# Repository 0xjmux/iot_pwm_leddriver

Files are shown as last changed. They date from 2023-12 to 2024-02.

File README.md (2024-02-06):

# IoT driver for "Dumb" 5050 RGB LED Strips
ESP8266-based LED Driver designed to work with WLED and cheap 12V barrel-jack power supplies for accent lighting around the home. 

<p align="center">

</p>

This driver was designed to allow network-enabled control of almost any 12V "dumb" strip around, from plain white to FCOB strips to RGBW. 

My v1.0 worked perfectly, so I'm going to leave it as-is. The only upgrades I'd make at this point are: 
1) WLED announced that they're deprecating ESP8266 support right after I ordered v1.0, but for driving a single color the ESP8266 should be more than enough. 
2) There's some whine from the Power mosfet drivers, but it's barely noticable and not really worth addressing unless I was already doing a redesign. 

***See [Releases](https://github.com/0xjmux/iot_pwm_leddriver/releases) for all the necessary files and information to make your own!***

### Features
* Uses mini blade fuses for overcurrent protection and to protect against fire hazard from shorts on bad quality LED strips
* Board designed to handle up to and above maximum expected from most LED strips (8A)
* 4 channels to handle RGBW: or up to 4 single-color strips
* Terminal block for ease of use connecting strips and a 2.1mm jack allowing use of cheap 12V supplies you have lying around
* Capable of both programming and debug over [SOICbite Connector](https://github.com/SimonMerrett/SOICbite).
* Includes status and power LEDs and board overvoltage protection

<p align="center">
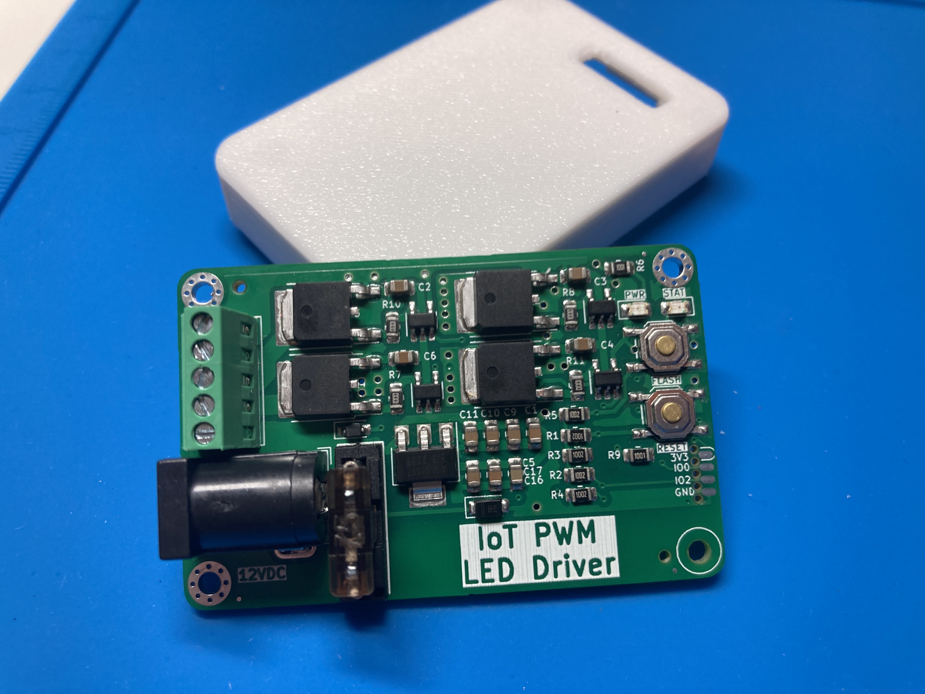
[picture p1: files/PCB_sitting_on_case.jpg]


</p>

* See [ABOUT.md](./ABOUT.md) for some information about design goals and the project. 

#### Pinout 

| Output | ESP Pin |
| ----- | ---  |
| LED_R | GPIO 5  |
| LED_G | GPIO 13 |
| LED_B | GPIO 14 |
| LED_W | GPIO 12 |
| STATUS LED | GPIO 16 |

#### Case
I also designed a 3D printable case, which can be found under [case/](case/). The screw terminals are still easily accessible, and there's a window on the bottom so you can see the board name and version without having to open it. 
* The case uses M2x8mm screws to hold the two halves together, and is designed to be printed in PLA with 10% infill. 

<p align="center">
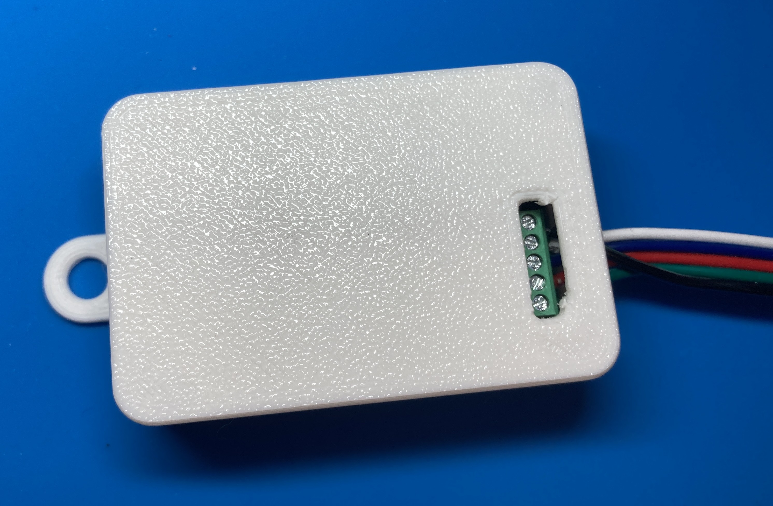
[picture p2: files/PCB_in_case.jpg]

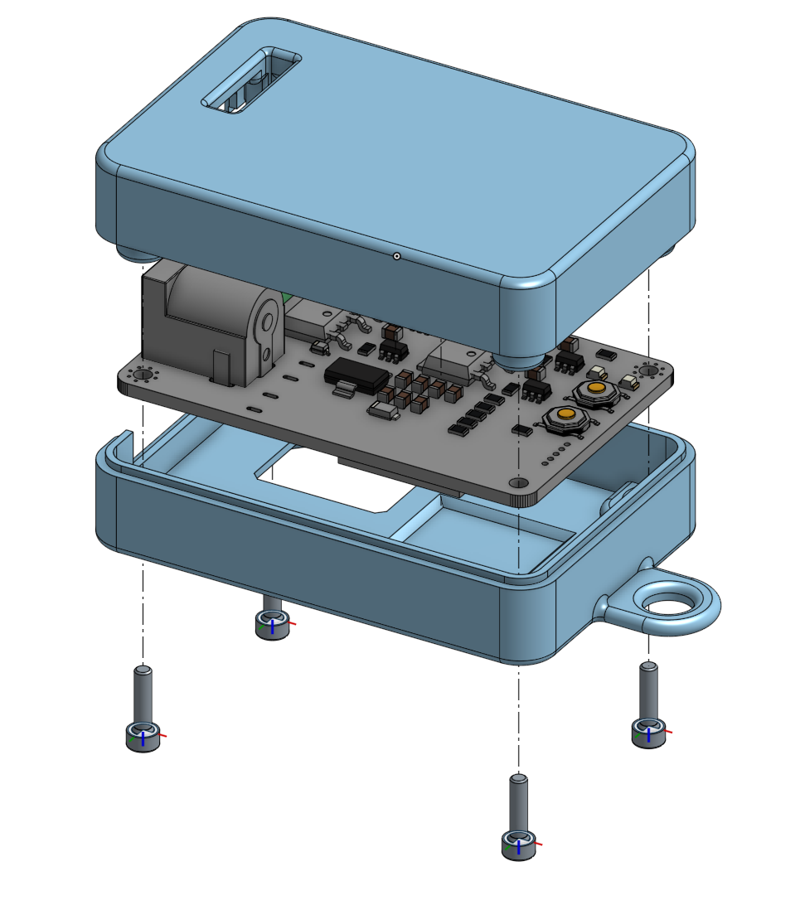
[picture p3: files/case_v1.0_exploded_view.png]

</p>

### v1.0 - First try works!
* Complete redesign from v0.2, with a focus on overall system design and ease of setup for the end user. 
* Uses mini blade fuses for overcurrent protection and to protect against fire hazard from shorts on bad quality LED strips
* Board designed to handle up to and above maximum expected from most LED strips (8A)
* 4 channels to handle RGBW: or up to 4 single-color strips
* Terminal block for ease of use connecting strips and a 2.1mm jack allowing use of cheap 12V supplies you have lying around
* Capable of both programming and debug over [SOICbite Connector](https://github.com/SimonMerrett/SOICbite).
* Includes status and power LEDs and board overvoltage protection

<p align="center">
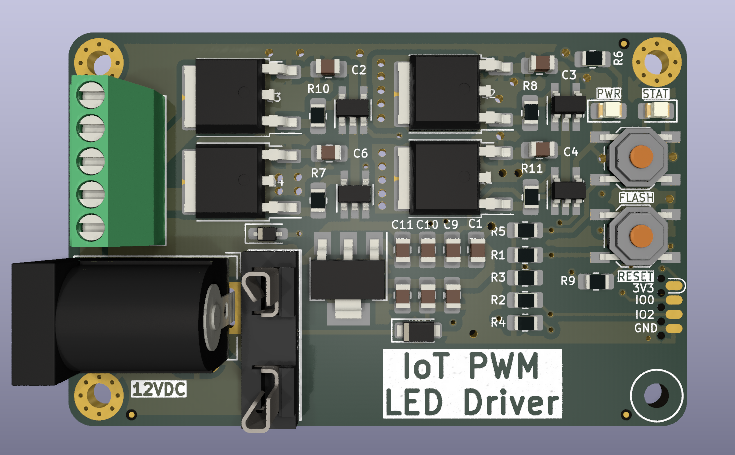
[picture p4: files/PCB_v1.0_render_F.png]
v1.0 PCB Render Front

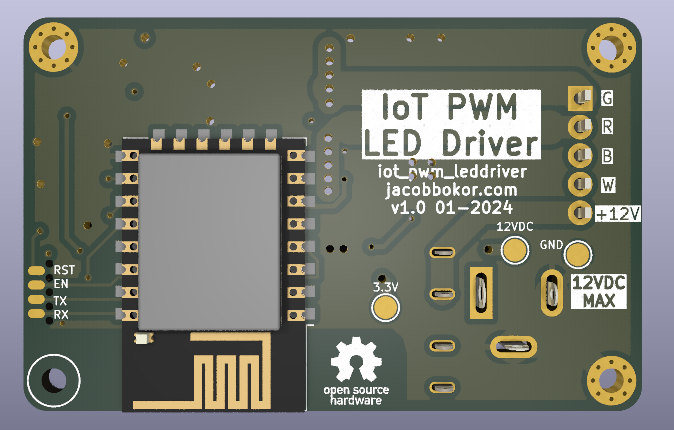
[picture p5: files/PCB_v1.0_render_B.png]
v1.0 PCB Render Back

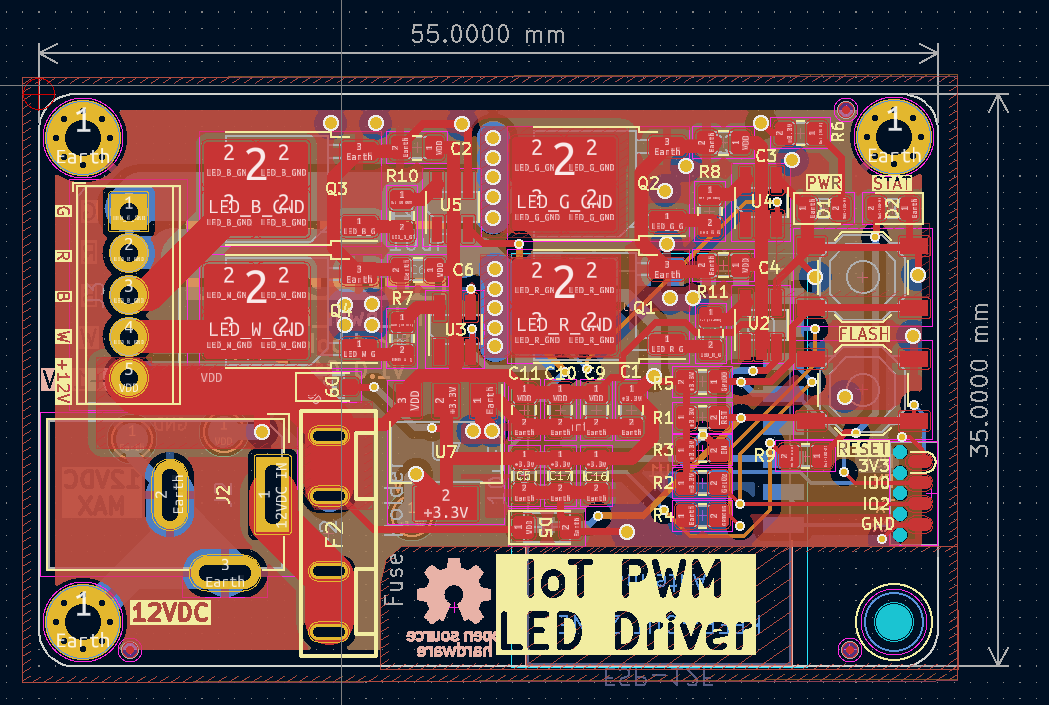
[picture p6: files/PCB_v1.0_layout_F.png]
v1.0 PCB Layout

</p>

### v0.1 - Quick Board Mock-up
* My first 4 layer board! But some improvement still possible
 
<p align="center">
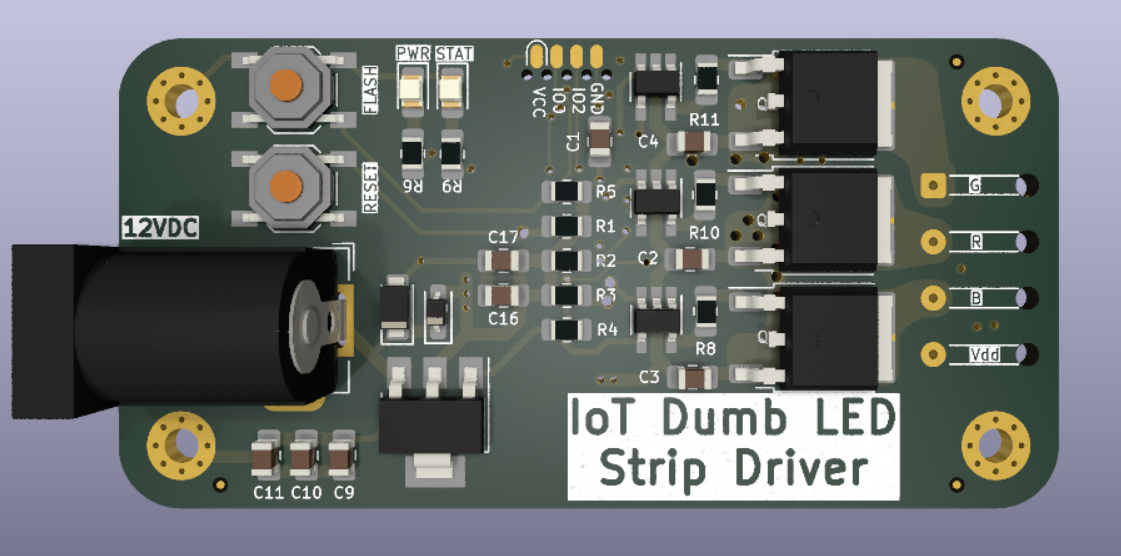
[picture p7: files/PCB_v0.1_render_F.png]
v0.1 PCB Render Front

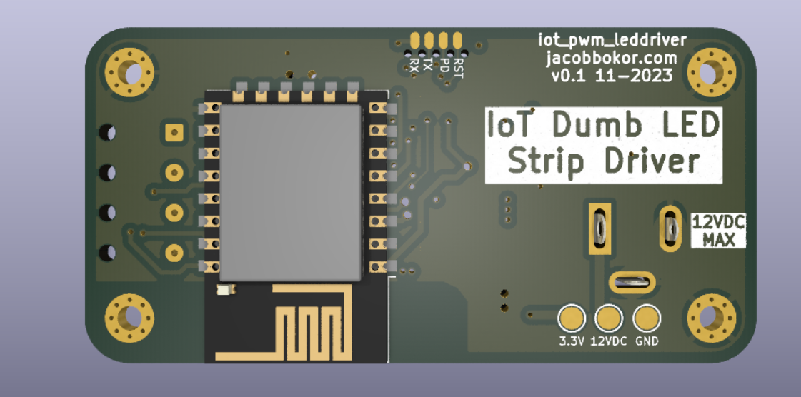
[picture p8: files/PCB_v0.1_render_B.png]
v0.1 PCB Render Back

</p>

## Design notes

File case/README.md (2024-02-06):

# PWM IoT LEDDriver Case

* Case is designed to be printed in PLA with 10% infill. Make sure both halves are oriented with their backs to the bed before clicking print. 

<p align="center">
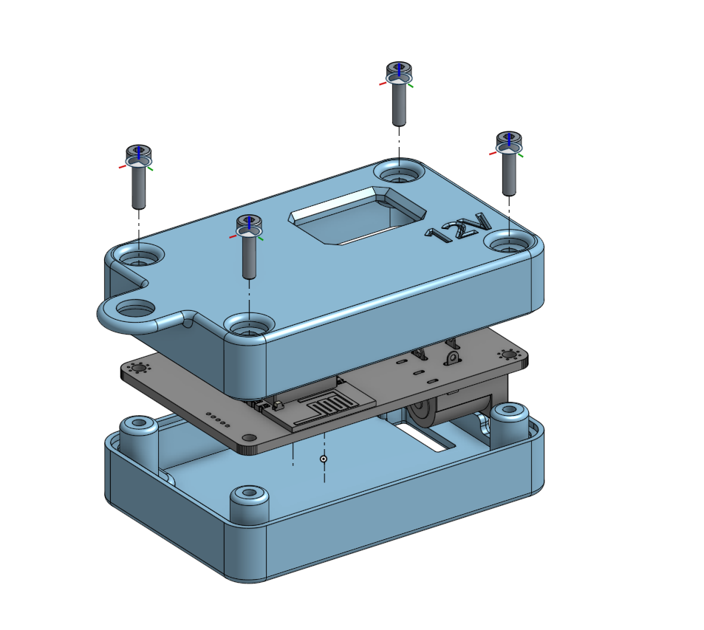
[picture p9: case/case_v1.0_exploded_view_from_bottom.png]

</p>

#### Top
<p align="center">
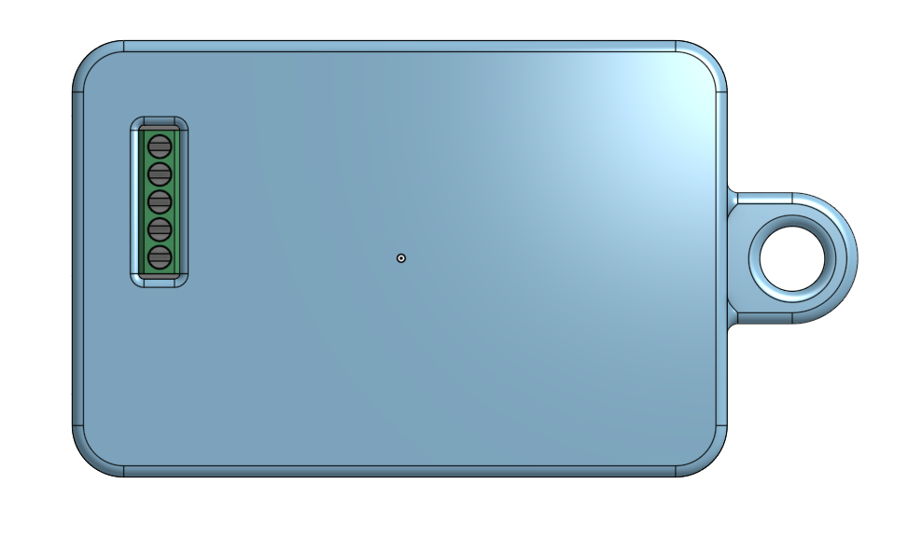
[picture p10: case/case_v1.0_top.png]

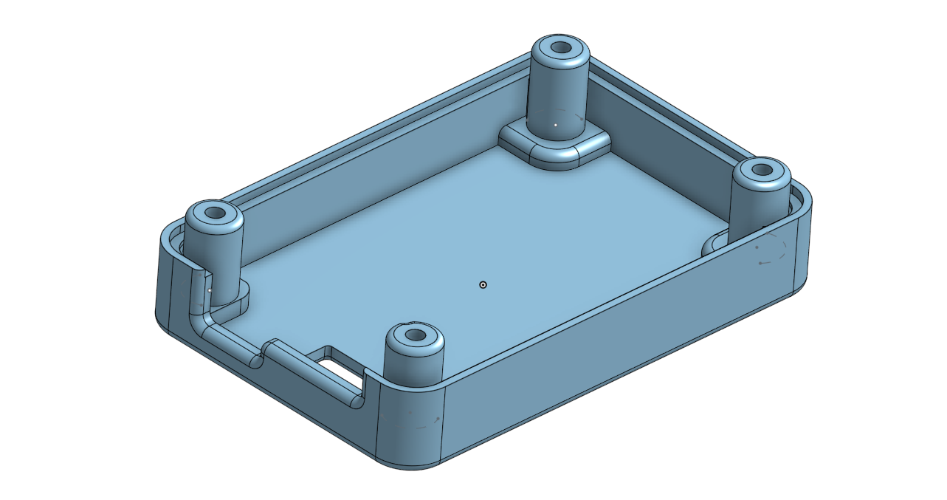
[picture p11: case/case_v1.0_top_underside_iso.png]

</p>

#### Bottom
<p align="center">
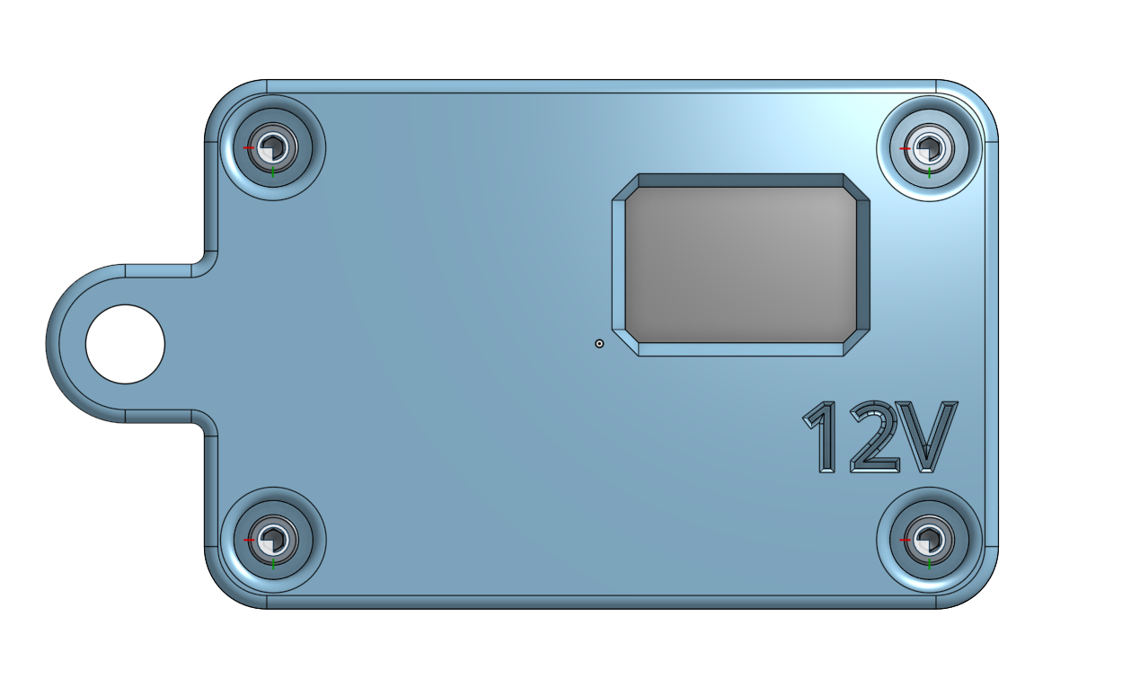
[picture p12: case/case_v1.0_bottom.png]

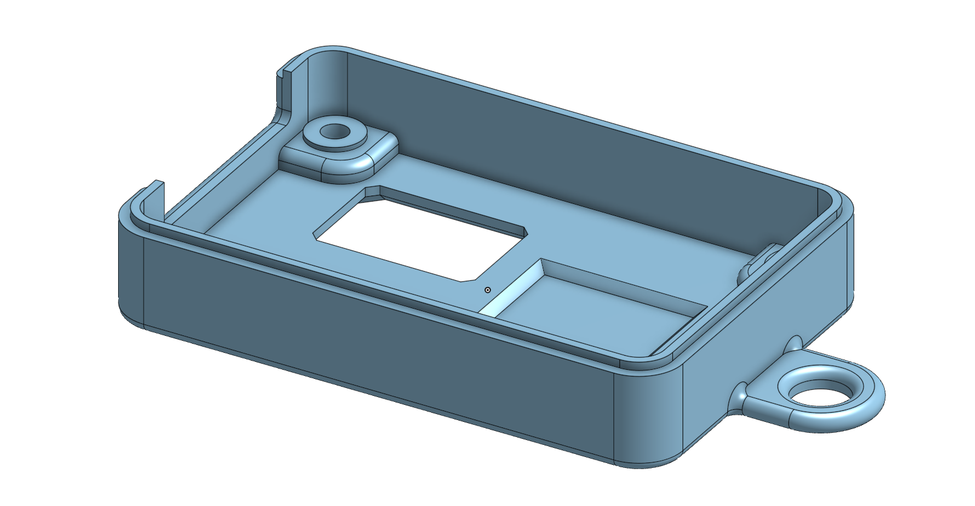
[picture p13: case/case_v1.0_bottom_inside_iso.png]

</p>

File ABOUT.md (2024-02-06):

This project follows up my previous [iot_leddriver_hw](https://github.com/0xjmux/iot_leddriver_hw) project, which was designed to control 5V WS2812B strips. 
It worked well, but I wanted to also be able to control the single color strips I had lying around, and wasn't able to find a suitable driver to do so. 
So, I set out to develop my own. 

#### Project Design Goals
When undertaking this project, I had the following goals in mind:
1. Low-cost and hand-assembleable, with a BOM goal of under $10.
2. Compact design, easily stowed away and hidden from view. Thoughtful system design, all ports on one side of PCB. 
3. Setting up the board with an LED strip must be self-explanatory for "non-technical" people, and the system design should guide them away from mistakes that result in hardware damage. 
4. Board must be safe on its own and should protect against problems with connected strips. This meant circuit protection, from both overvoltage and shorts.
5. Wi-Fi connected using ESP module, and compatible with WLED for easy control and integration with existing setups. 
6. Should be able to control any type of "dumb" 12V strip, from single color to RGBW

#### Project TODO:
* convert to ESP32-C3 - right after I ordered my first set of boards WLED 1.14 came out, and they're deprecating ESP8266 support. Whoops. 
* fix coil whine from power mosfet drivers
*

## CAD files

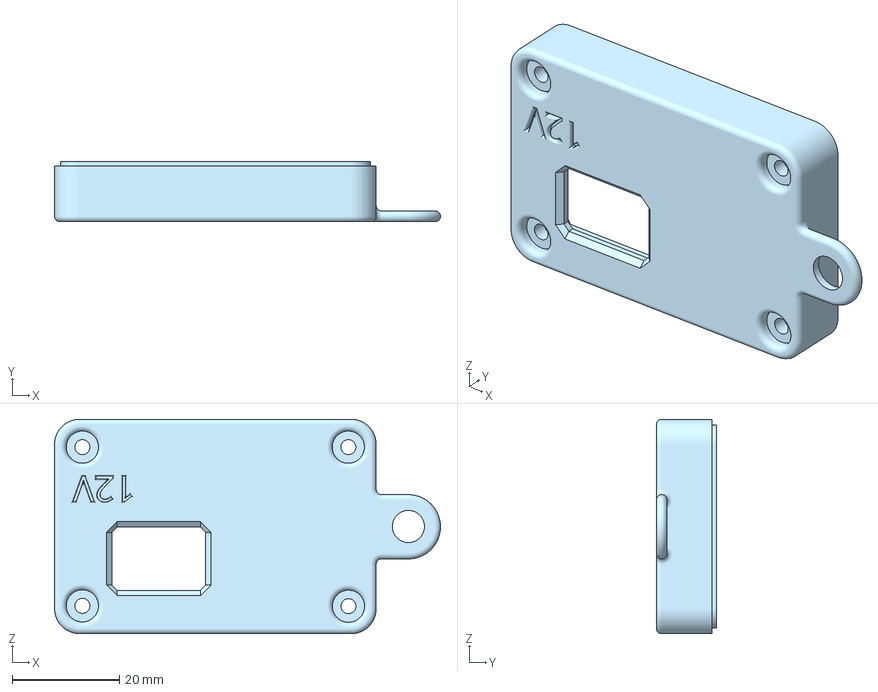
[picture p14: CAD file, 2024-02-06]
case/iot_pwmled_case_bottom_v1.0.3mf
72.0 x 11.2 x 40.0 mm

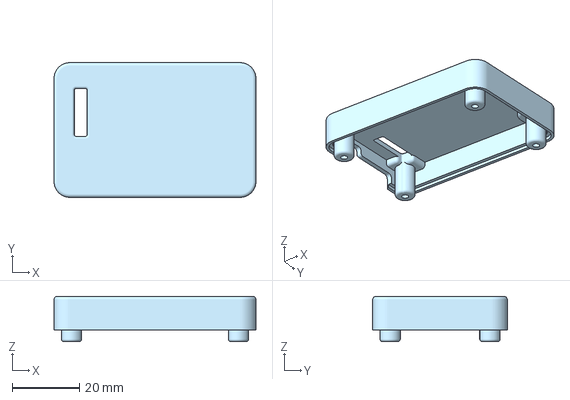
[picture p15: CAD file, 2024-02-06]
case/iot_pwmled_case_top_v1.0.3mf
60.0 x 40.0 x 13.5 mm

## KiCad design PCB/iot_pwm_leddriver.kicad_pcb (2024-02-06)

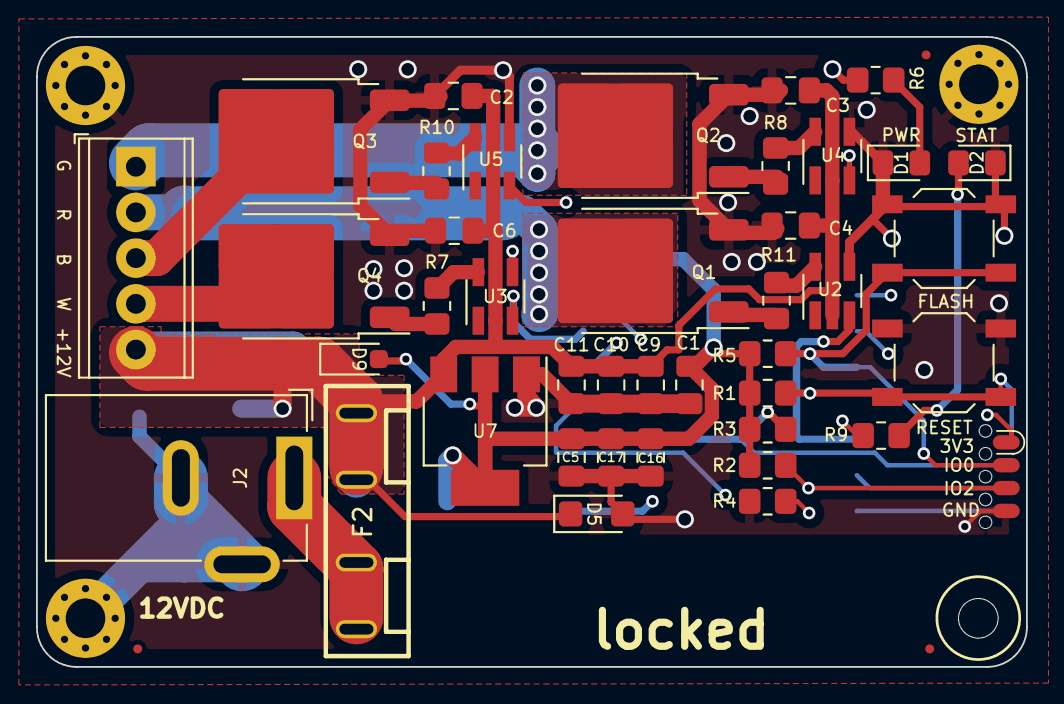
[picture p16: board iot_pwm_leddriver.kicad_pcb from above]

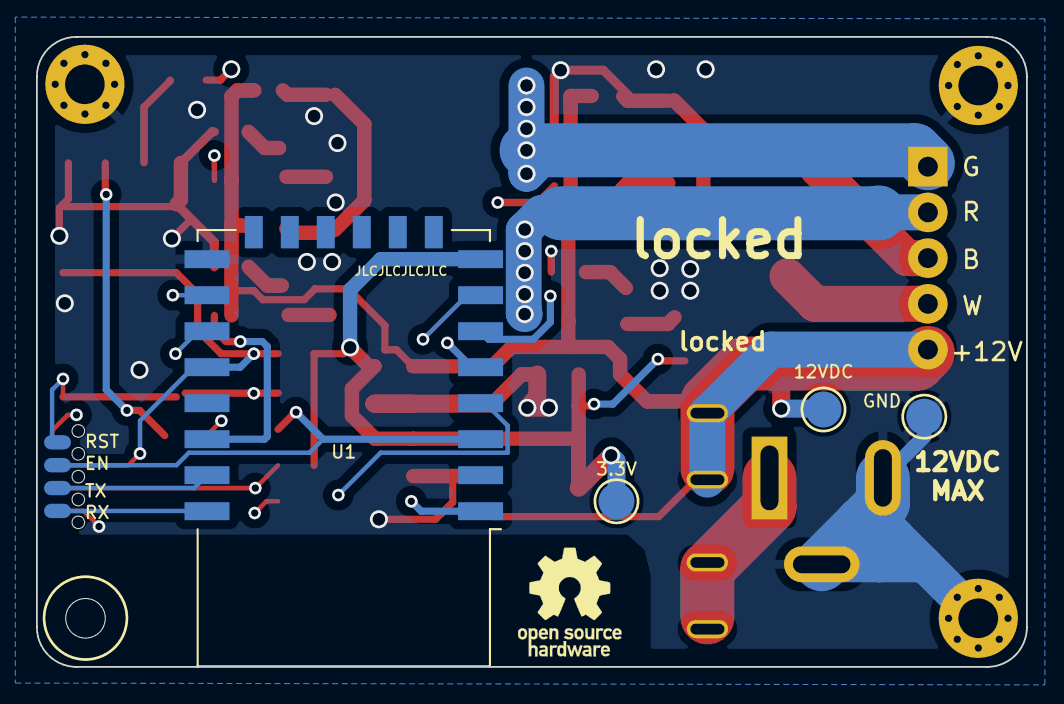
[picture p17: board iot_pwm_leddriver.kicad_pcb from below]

Board: 4 copper layers, 55.0 x 35.0 mm, 52 parts (4 on the bottom side), 30 nets.

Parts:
C1, C2, C3, C4, C5, C6, C9, C10, C11, C17: 10uF; C_0805_2012Metric_Pad1.18x1.45mm_HandSolder
C16: 100nF; C_0805_2012Metric_Pad1.18x1.45mm_HandSolder
D1: PWR; LED_0805_2012Metric_Pad1.15x1.40mm_HandSolder
D2: STAT; LED_0805_2012Metric_Pad1.15x1.40mm_HandSolder
D5: SMF12A; D_SMF
D9: 1N5819WS; D_SOD-323_HandSoldering
F2: Fuse Holder; FUSE-TH_XF-505P
FID1, FID2, FID3: Fiducial; Fiducial_0.5mm_Mask1mm
H1, H3, H4: MountingHole_Pad; MountingHole_2.2mm_M2_Pad_Via
H2: Non-via mounting hole; MountingHole_2.2mm_M2_ISO7380
J1: ProgConn-SOICBite; SOIC_clipProgESP8266
J2: 12V PWR; BarrelJack_GCT_DCJ200-10-A_Horizontal
J3: LED_GRBWA; TerminalBlock_Phoenix_MPT-0,5-5-2.54_1x05_P2.54mm_Horizontal
Q1, Q2, Q3, Q4: UMW30N06; TO-252-2
R1, R2, R3, R4, R5: 10k; R_0805_2012Metric_Pad1.20x1.40mm_HandSolder
R6, R9: 1k; R_0805_2012Metric_Pad1.20x1.40mm_HandSolder
R7, R8, R10, R11: 100; R_0805_2012Metric_Pad1.20x1.40mm_HandSolder
SW1: RESET; SW_SPST_TL3342
SW2: FLASH; SW_SPST_TL3342
TP3: 12VDC; TestPoint_Pad_D2.0mm
TP5: 3.3V; TestPoint_Pad_D2.0mm
TP6: GND; TestPoint_Pad_D2.0mm
U1: ESP-12F; ESP-12E
U2, U3, U4, U5: MCP1416; SOT-23-5_HandSoldering
U7: AMS1117-3.3; SOT-223-3_TabPin2

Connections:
+3.3V: C1.1, C5.1, C16.1, C17.1, D9.2 (A), J1.1 (VCC), R1.1, R2.1, R3.1, R5.2, R6.2, TP5.1, U1.8 (VCC), U7.2 (VO)
/12VDC IN: F2.1, J2.1
/GPIO0: J1.2 (GPIO0), R5.1, SW2.2, U1.18 (GPIO0)
/LED Driver/LED_B: U1.5 (GPIO14), U5.3 (IN)
/LED Driver/LED_B_G: Q3.1 (G), R10.2
/LED Driver/LED_B_GND: J3.3 (BK), Q3.2 (D)
/LED Driver/LED_G: U1.7 (GPIO13), U4.3 (IN)
/LED Driver/LED_G_G: Q2.1 (G), R8.2
/LED Driver/LED_G_GND: J3.1 (GK), Q2.2 (D)
/LED Driver/LED_R: U1.20 (GPIO5), U2.3 (IN)
/LED Driver/LED_R_G: Q1.1 (G), R11.2
/LED Driver/LED_R_GND: J3.2 (RK), Q1.2 (D)
/LED Driver/LED_W: U1.6 (GPIO12), U3.3 (IN)
/LED Driver/LED_W_G: Q4.1 (G), R7.2
/LED Driver/LED_W_GND: J3.4 (W), Q4.2 (D)
/RX: J1.5 (RX), U1.22 (GPIO1/TXD)
/TX: J1.6 (TX), U1.21 (GPIO3/RXD)
/~RST: J1.8 (RST), R1.2, SW1.2, U1.1 (~RST)
EN: J1.7 (CH_PD), R3.2, U1.3 (EN)
Earth: C1.2, C2.2, C3.2, C4.2, C5.2, C6.2, C9.2, C10.2, C11.2, C16.2, C17.2, D1.1 (K), D2.1 (K), D5.2 (A2), H1.1, H3.1, H4.1, J1.4 (GND), J2.2, J2.3, Q1.3 (S), Q2.3 (S), Q3.3 (S), Q4.3 (S), R4.1, SW1.1, SW2.1, TP6.1, U1.15 (GND), U2.4 (GND), U3.4 (GND), U4.4 (GND), U5.4 (GND), U7.1 (GND)
GPIO2: J1.3 (GPIO2), R2.2, U1.17 (GPIO2)
GPIO15: R4.2, U1.16 (GPIO15)
unnamed: D1.2 (A), R6.1
unnamed: D2.2 (A), R9.1
unnamed: R9.2, U1.4 (GPIO16)
unnamed: R11.1, U2.5 (OUT)
unnamed: R7.1, U3.5 (OUT)
unnamed: R8.1, U4.5 (OUT)
unnamed: R10.1, U5.5 (OUT)
VDD: C2.1, C3.1, C4.1, C6.1, C9.1, C10.1, C11.1, D5.1 (A1), D9.1 (K), F2.2, J3.5 (A), TP3.1, U2.2 (Vdd), U3.2 (Vdd), U4.2 (Vdd), U5.2 (Vdd), U7.3 (VI)

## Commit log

2023-12-23 first commit with initial PCB rev
    [LED_driver.kicad_sch, Power_and_board.kicad_sch, dumb-led-driver.kicad_pcb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]
2023-12-23 changed mounting holes to ones without fiducials and fixed power calculation
    [LED_driver.kicad_sch, Power_and_board.kicad_sch]
2023-12-23 added silkscreen to board and pictures to readme
    [dumb-led-driver.kicad_pcb]
2023-12-24 Redesign around new components added to scheamtic
    - shift left most of board
    - re-layout
    - new components
    - drc passes (mostly)
    [Power_and_board.kicad_sch, dumb-led-driver.kicad_pcb]
2023-12-26 fuse added to schematic. began board re-layout
    [LED_driver.kicad_sch, Power_and_board.kicad_sch, dumb-led-driver.kicad_pcb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]
2023-12-26 began rev2 of layout. board size will have to be increased
    - will need to make compomises regarding I/O, wont be able to make both power in and out fit on same short side :(
    [LED_driver.kicad_sch, Power_and_board.kicad_sch, dumb-led-driver.kicad_pcb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]
2024-01-08 design v1.0 - complete redesign
    * redid schematic
    * changed to screw terminal
    * added W channel for RGBW strips
    * did layout
    [LED_driver.kicad_sch, Power_and_board.kicad_sch, dumb-led-driver.kicad_pcb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]
2024-01-08 schematic and layout cleanup
    * plus BOM finalization
    [LED_driver.kicad_sch, Power_and_board.kicad_sch, iot_pwm_leddriver.csv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]
2024-01-12 v1.0 ordered! README updated, with everything else
    Boards were ordered. All requisite files added, and a basic README set
    up talking about the project.
    [Power_and_board.kicad_sch, iot_pwm_leddriver.csv, iot_pwm_leddriver.kicad_sch]
2024-02-06 detailed project readme
    [iot_pwm_leddriver.kicad_pcb, iot_pwm_leddriver.kicad_sch, iot_pwmled_case_bottom_v1.0.3mf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]
